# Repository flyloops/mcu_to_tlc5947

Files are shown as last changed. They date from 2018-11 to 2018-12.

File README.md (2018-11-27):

# mcu_to_tlc5947 
A simple PCB for connecting an Arduino (Teensy or Nano) to the Adafruit TLC5947 PWM LED Driver. In progress. 

* [Teensy schematic (PDF)](teensy/mcu_to_tlc5947.pdf)
* [Teensy bill-of-materials](teensy/BOM.txt)

# Top View: 
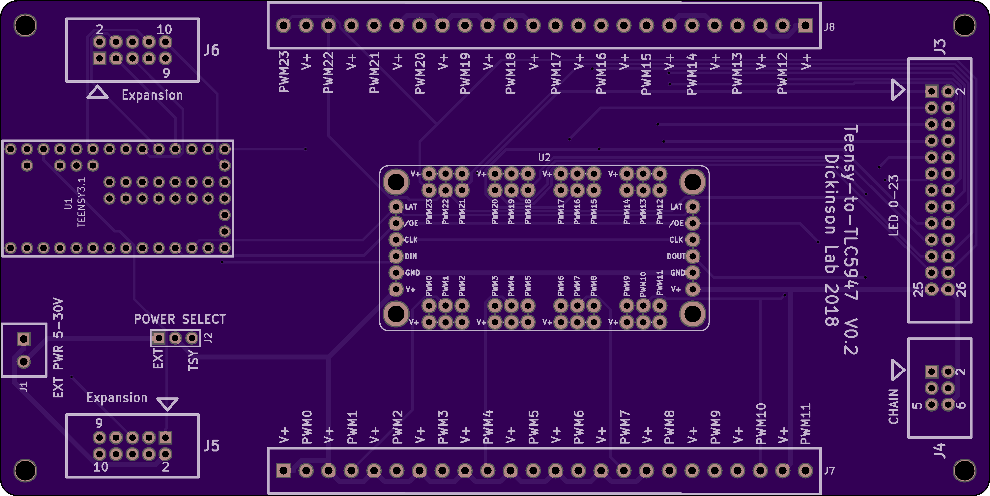
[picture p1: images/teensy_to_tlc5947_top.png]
top_view


# Bottom View:
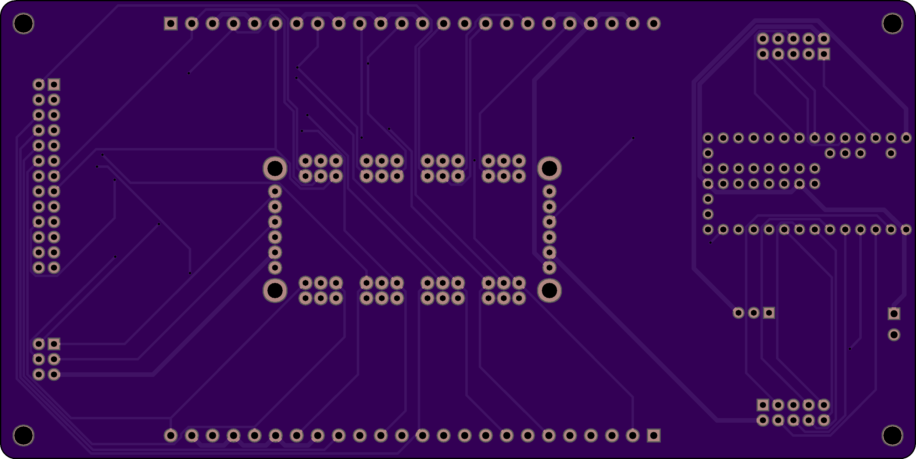
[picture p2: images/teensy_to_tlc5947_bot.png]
bot_view


# License: 
Creative Commons Attribution 4.0 International CC BY 4.0

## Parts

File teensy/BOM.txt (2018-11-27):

Components
##########

Part        Description                  Package      Vendor     Part Number                   Qty
----        -----------                  -------      ------     -----------                   ---
J1,J7,J8    terminal block, 2-pos        custom       Digikey    ED2635-ND                     25
J2          break away header 0.1"       NA           Digikey    S1011EC-40-ND                 1
J3          13x2 shrouhded header        NA           Digikey    S9173-ND                      1 
J4          3x2 shrouded header          NA           Digikey    732-5394-ND                   1
J5,J6       5x2 shrouded header          NA           Digikey    S9169-ND                      2
U1          Teensy 3.2 dev board         custom       PJRC       teensy 3.2                    1
U2          Adafruit 24-Chan LED driver  custom       Adafruit   1429                          1    
            3x2 male header              NA           Digikey    609-3234-ND                   8 
            3x2 female header            NA           Digikey    609-6001-ND                   8
            6x1 female header            NA           Digikey    S7004-ND                      2
            break away header 0.1"       NA           Digikey    S1011EC-40-ND                 1

Accessories
###########

Description                                Vendor     Part Number                   Qty
-----------                                ------     -----------                   ---
3x2 IDC cable connector                    Digikey    732-5394-ND                   2
5x2 IDC cable connector                    Digieky    S9306-ND                      2
13x2 IDC cable connector                   Digikey    S9291-ND                      2
26 conductor ribbon cable 0.005" pitch     Digikey    AE26G-5-ND                    1 (5')

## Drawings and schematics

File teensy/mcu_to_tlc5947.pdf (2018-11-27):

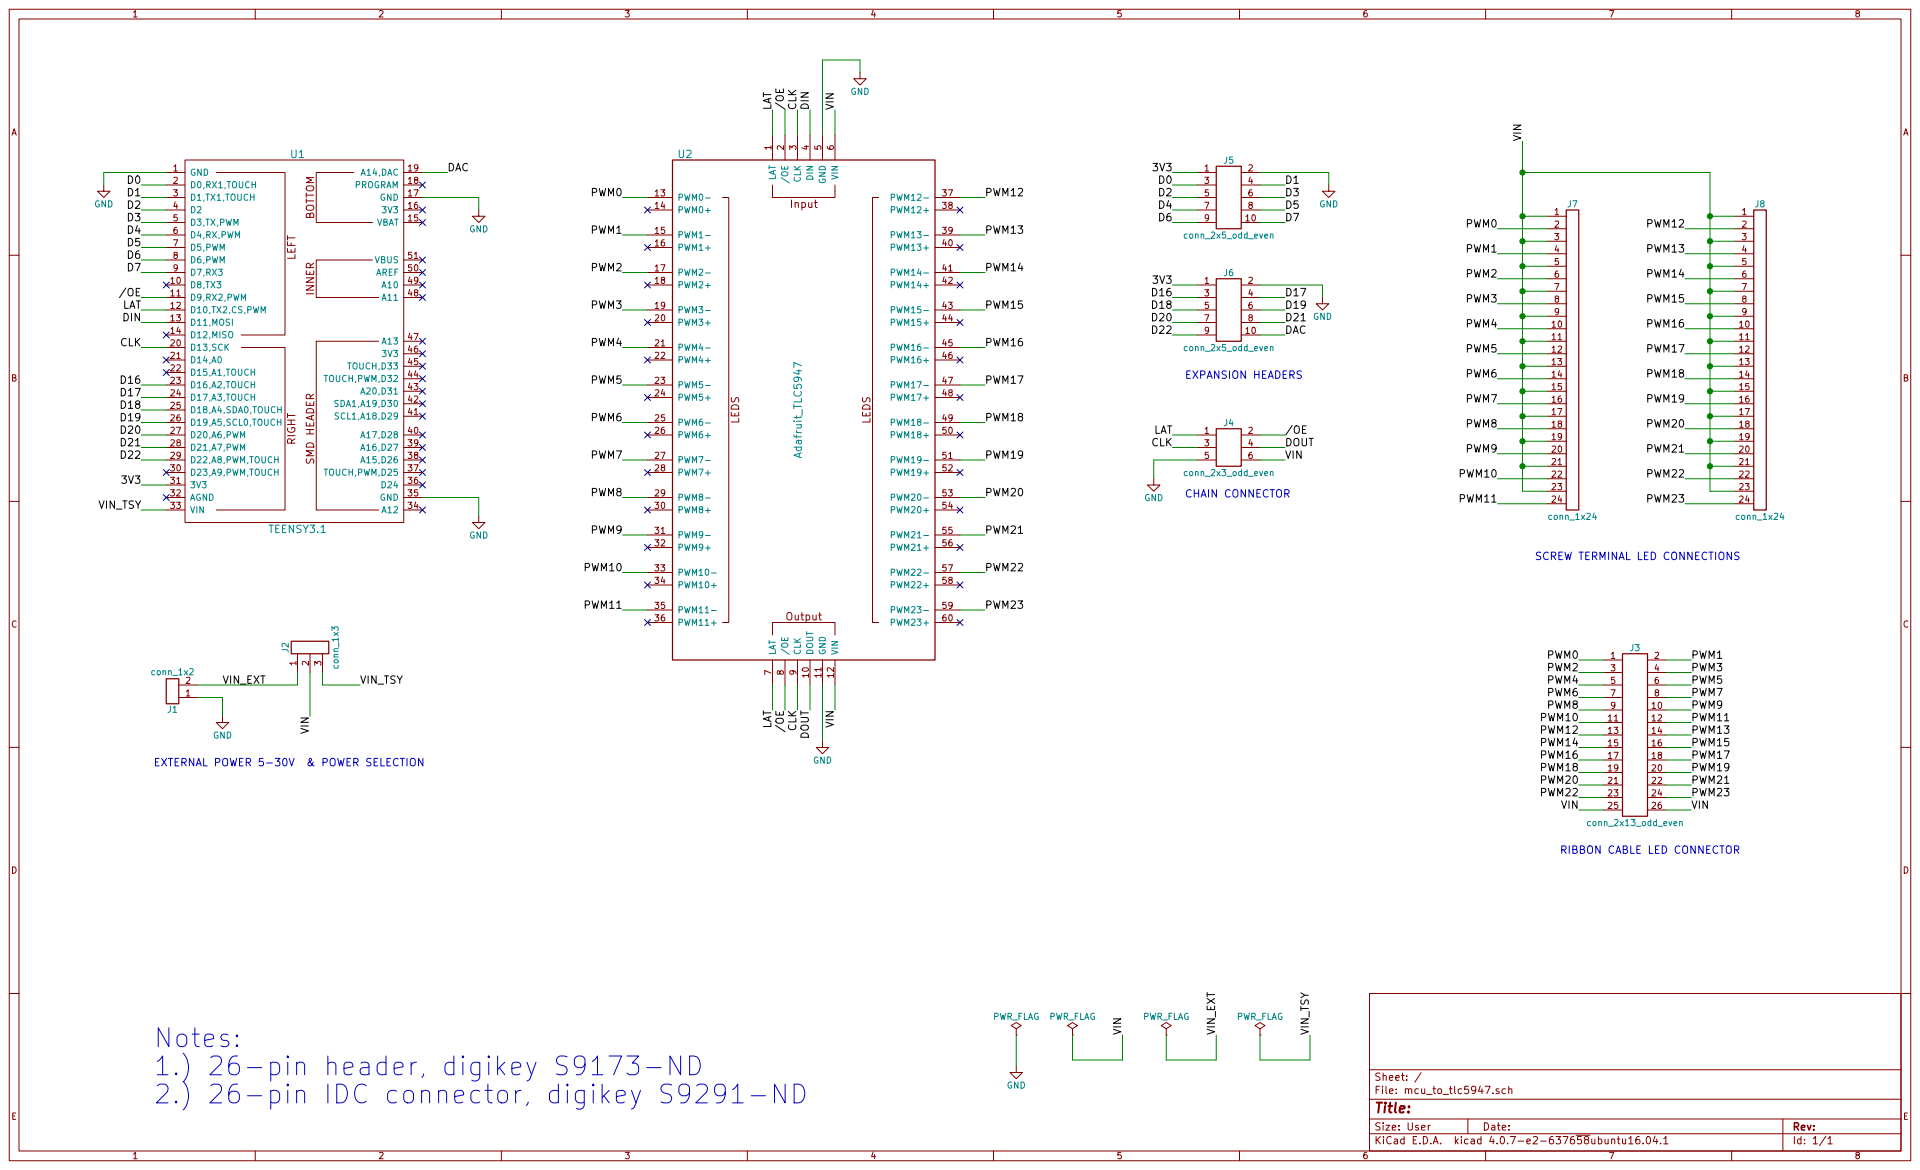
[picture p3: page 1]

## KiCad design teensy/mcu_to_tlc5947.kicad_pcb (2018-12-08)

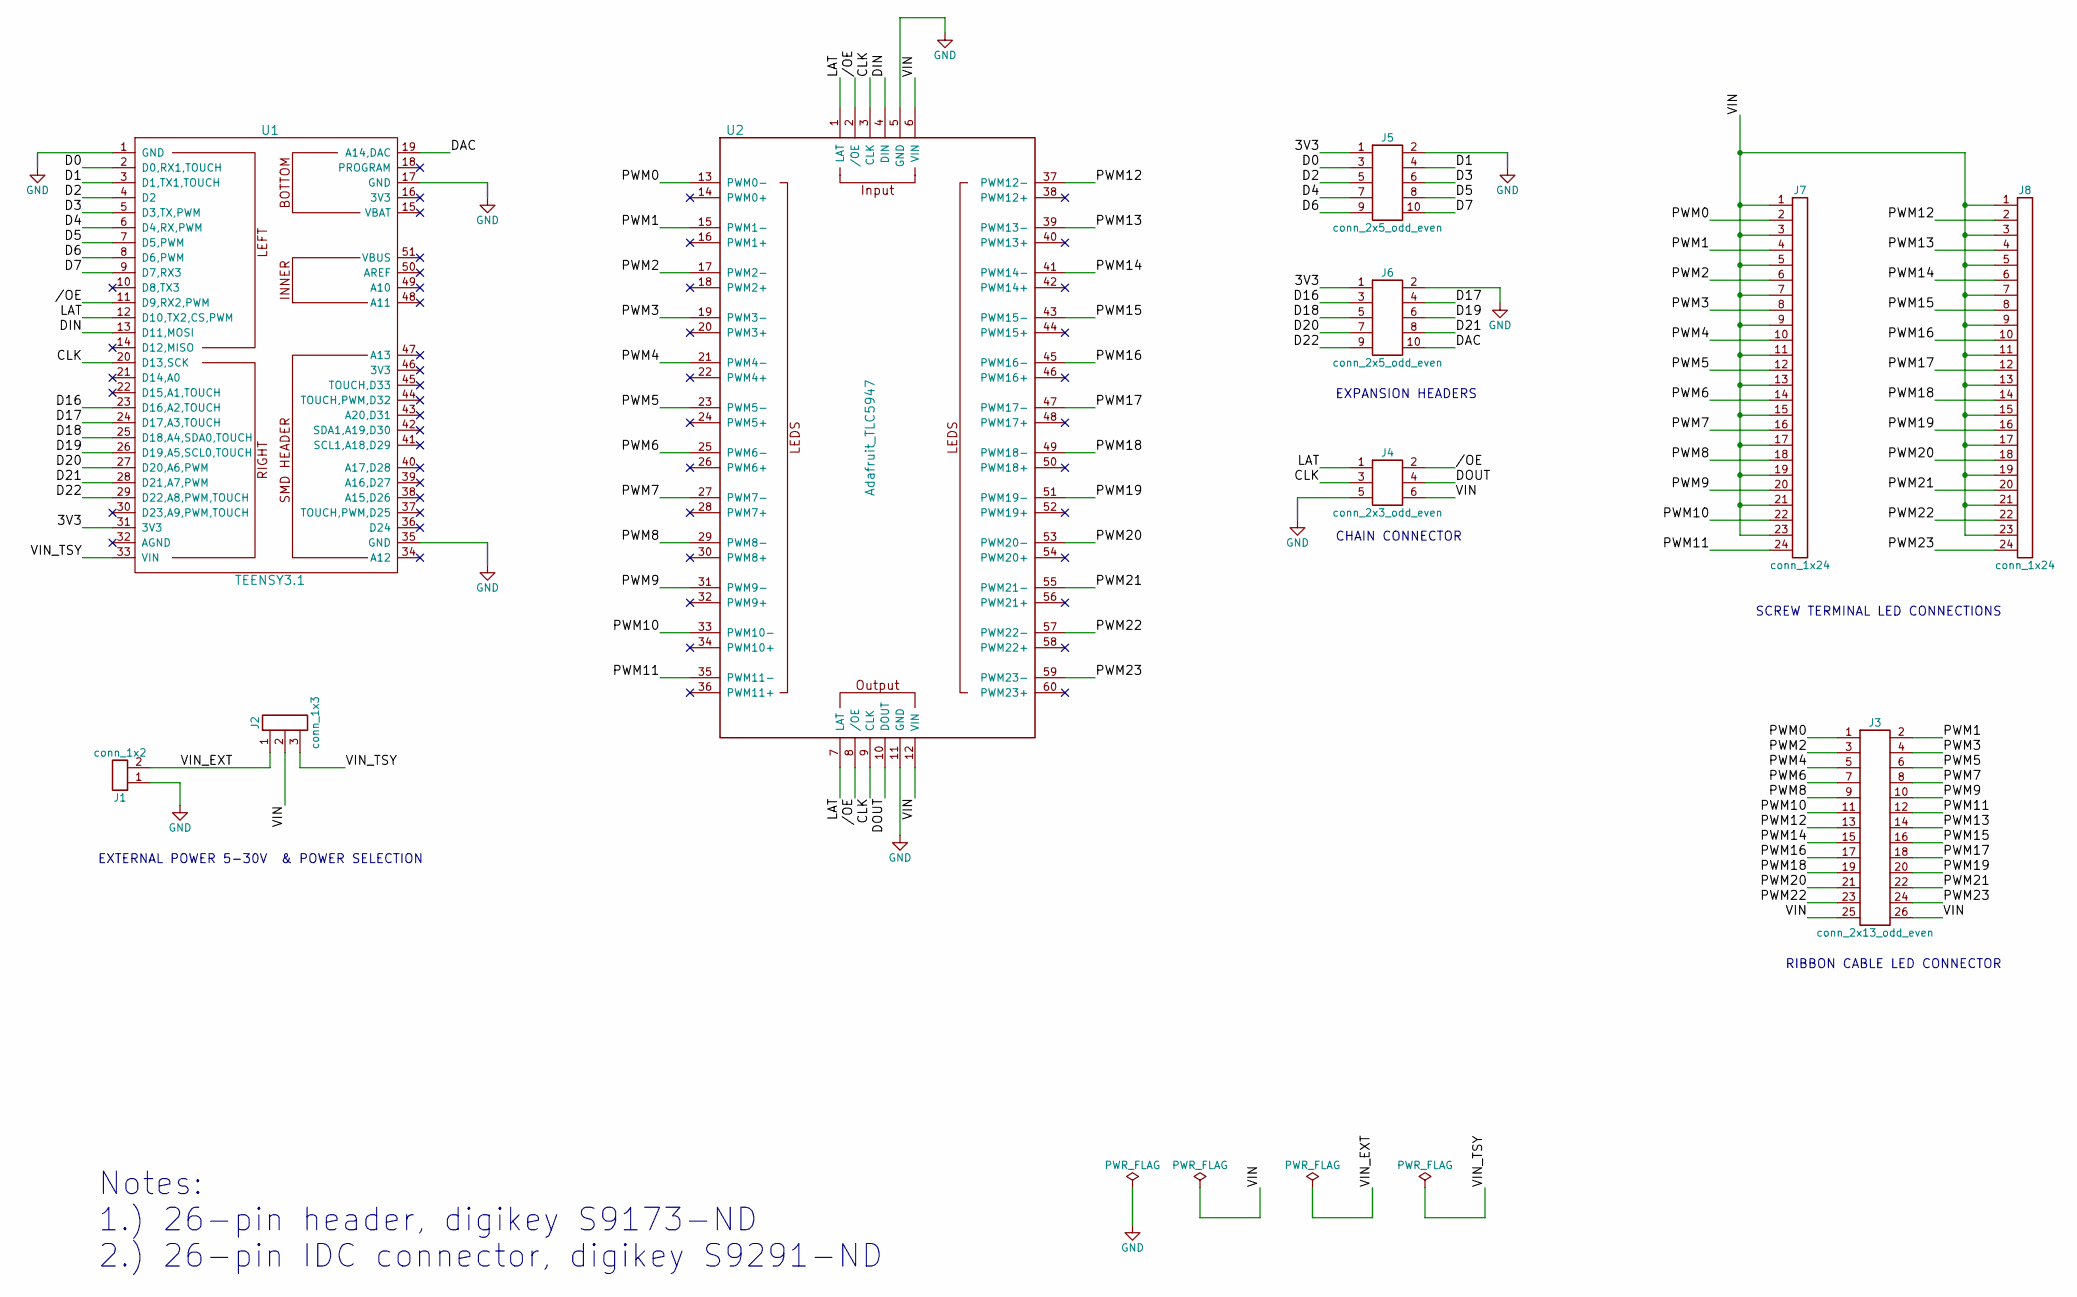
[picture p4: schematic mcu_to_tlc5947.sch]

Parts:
J1: conn_1x2; BLOCK_CONN_2X1
J2: conn_1x3; PIN_ARRAY_1X3
J3: conn_2x13_odd_even; 5X2_SHRD_HEADER
J4: conn_2x3_odd_even; 3X2_SHRD_HEADER
J5, J6: conn_2x5_odd_even; 5X2_SHRD_HEADER
J7, J8: conn_1x24; BLOCK_CONN_2X1
U1: TEENSY3.1; TEENSY3X
U2: Adafruit_TLC5947

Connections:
/3V3: J5.1, J6.1, U1.31 (3V3)
//OE: J4.2, U1.11 (D9,RX2,PWM), U2.2 (/OE), U2.8 (/OE)
/CLK: J4.3, U1.20 (D13,SCK), U2.3 (CLK), U2.9 (CLK)
/D0: J5.3, U1.2 (D0,RX1,TOUCH)
/D1: J5.4, U1.3 (D1,TX1,TOUCH)
/D2: J5.5, U1.4 (D2)
/D3: J5.6, U1.5 (D3,TX,PWM)
/D4: J5.7, U1.6 (D4,RX,PWM)
/D5: J5.8, U1.7 (D5,PWM)
/D6: J5.9, U1.8 (D6,PWM)
/D7: J5.10, U1.9 (D7,RX3)
/D16: J6.3, U1.23 (D16,A2,TOUCH)
/D17: J6.4, U1.24 (D17,A3,TOUCH)
/D18: J6.5, U1.25 (D18,A4,SDA0,TOUCH)
/D19: J6.6, U1.26 (D19,A5,SCL0,TOUCH)
/D20: J6.7, U1.27 (D20,A6,PWM)
/D21: J6.8, U1.28 (D21,A7,PWM)
/D22: J6.9, U1.29 (D22,A8,PWM,TOUCH)
/DAC: J6.10, U1.19 (A14,DAC)
/DIN: U1.13 (D11,MOSI), U2.4 (DIN)
/DOUT: J4.4, U2.10 (DOUT)
/LAT: J4.1, U1.12 (D10,TX2,CS,PWM), U2.1 (LAT), U2.7 (LAT)
/PWM0: J3.1, J7.2, U2.13 (PWM0-)
/PWM1: J3.2, J7.4, U2.15 (PWM1-)
/PWM2: J3.3, J7.6, U2.17 (PWM2-)
/PWM3: J3.4, J7.8, U2.19 (PWM3-)
/PWM4: J3.5, J7.10, U2.21 (PWM4-)
/PWM5: J3.6, J7.12, U2.23 (PWM5-)
/PWM6: J3.7, J7.14, U2.25 (PWM6-)
/PWM7: J3.8, J7.16, U2.27 (PWM7-)
/PWM8: J3.9, J7.18, U2.29 (PWM8-)
/PWM9: J3.10, J7.20, U2.31 (PWM9-)
/PWM10: J3.11, J7.22, U2.33 (PWM10-)
/PWM11: J3.12, J7.24, U2.35 (PWM11-)
/PWM12: J3.13, J8.2, U2.37 (PWM12-)
/PWM13: J3.14, J8.4, U2.39 (PWM13-)
/PWM14: J3.15, J8.6, U2.41 (PWM14-)
/PWM15: J3.16, J8.8, U2.43 (PWM15-)
/PWM16: J3.17, J8.10, U2.45 (PWM16-)
/PWM17: J3.18, J8.12, U2.47 (PWM17-)
/PWM18: J3.19, J8.14, U2.49 (PWM18-)
/PWM19: J3.20, J8.16, U2.51 (PWM19-)
/PWM20: J3.21, J8.18, U2.53 (PWM20-)
/PWM21: J3.22, J8.20, U2.55 (PWM21-)
/PWM22: J3.23, J8.22, U2.57 (PWM22-)
/PWM23: J3.24, J8.24, U2.59 (PWM23-)
/VIN: J2.2, J3.25, J3.26, J4.6, J7.1, J7.3, J7.5, J7.7, J7.9, J7.11, J7.13, J7.15, J7.17, J7.19, J7.21, J7.23, J8.1, J8.3, J8.5, J8.7, J8.9, J8.11, J8.13, J8.15, J8.17, J8.19, J8.21, J8.23, U2.6 (VIN), U2.12 (VIN)
/VIN_EXT: J1.2, J2.1
/VIN_TSY: J2.3, U1.33 (VIN)
GND: J1.1, J4.5, J5.2, J6.2, U1.1 (GND), U1.17 (GND), U1.35 (GND), U2.5 (GND), U2.11 (GND)

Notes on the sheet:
CHAIN CONNECTOR
EXTERNAL POWER 5-30V & POWER SELECTION
SCREW TERMINAL LED CONNECTIONS
RIBBON CABLE LED CONNECTOR
EXPANSION HEADERS
Notes: 1.) 26-pin header, digikey S9173-ND 2.) 26-pin IDC connector, digikey S9291-ND

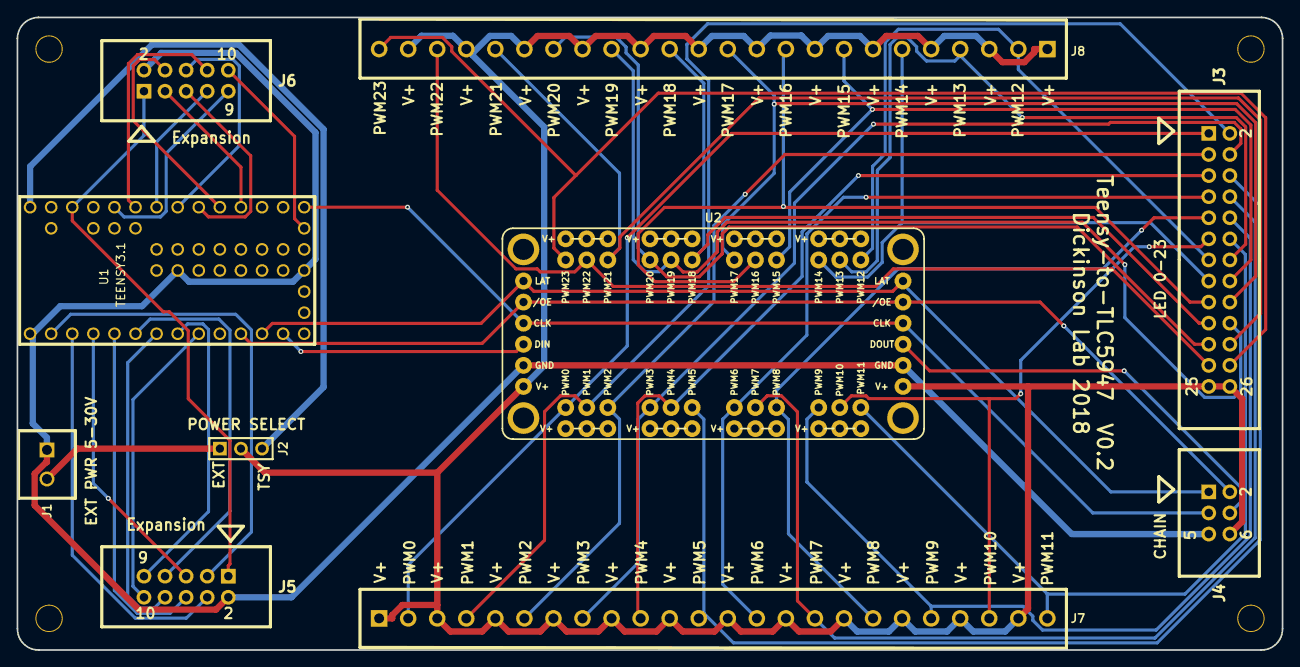
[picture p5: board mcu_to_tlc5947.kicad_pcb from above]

Board: 2 copper layers, 152.4 x 76.2 mm, 14 parts (0 on the bottom side), 50 nets.

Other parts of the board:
M1, M2, M3, M4: VAL**; MOUNT_HOLE_4_40

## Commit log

2018-11-17 Project creation.
    [mcu_to_tlc5947.kicad_pcb, mcu_to_tlc5947.sch]
2018-11-20 Completed initial version of design. Created version 0.1 gerber files.
    [mcu_to_tlc5947-B.Cu.gbr, mcu_to_tlc5947-B.Mask.gbr, mcu_to_tlc5947-B.SilkS.gbr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]
2018-11-26 Added BOM.
2018-11-27 Added missing parts to BOM and added pdf of schematic.
2018-12-08 Fixed error with adafruit tlc5947 foot print.
    [mcu_to_tlc5947-B.Cu.gbr, mcu_to_tlc5947-B.Mask.gbr, mcu_to_tlc5947-B.SilkS.gbr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]
2018-12-21 Update the pcb images.
